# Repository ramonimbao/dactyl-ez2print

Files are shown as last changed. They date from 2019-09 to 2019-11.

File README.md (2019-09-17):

# Dactyl EZ-to-Print

An easy-to-print ortholinear [dactyl](https://github.com/adereth/dactyl-keyboard)-like keyboard that requires no support! An accompanying blog post can be found [here](https://ramonimbao.github.io/ergodox-easy/).

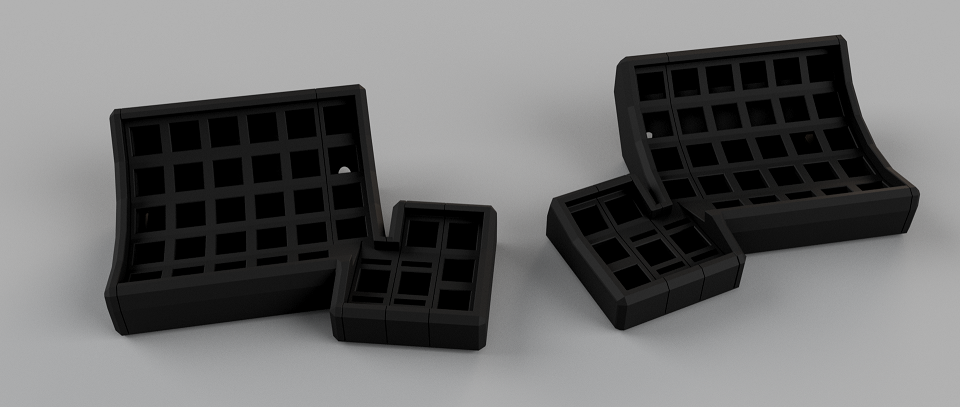
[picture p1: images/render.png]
Left side 3D printed


## Printing

Print the STL files as oriented. No support generation required. If exported from Fusion 360, a certain face of each part has a 0.4 mm chamfer to account for [elephant's foot](https://all3dp.com/2/elephant-s-foot-3d-printing-problem-easy-fixes/). Orient the part such that that face is the bottom.

## Hardware

These files were designed for the blue Arduino Pro Micro and the [RS Pro 805-1661 4-pole composite video jack](https://octopart.com/8051661-rs+pro-103323509) in mind, which is a mistake because I thought those were TRRS jacks! Anyway, besides those two and the 3D prints, the additional hardware you need are:

- 1× M3×25 countersunk head screw
- 10× M3×16 countersunk head screw
- 2× M3×10 countersunk head screw
- 2× M3×8 countersunk head screw

Quantities are for one half only.

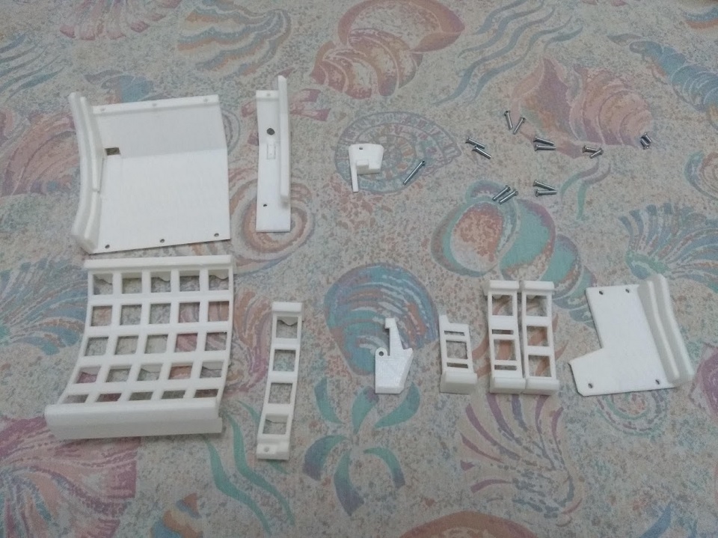
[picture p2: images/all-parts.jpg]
All parts


## Assembly

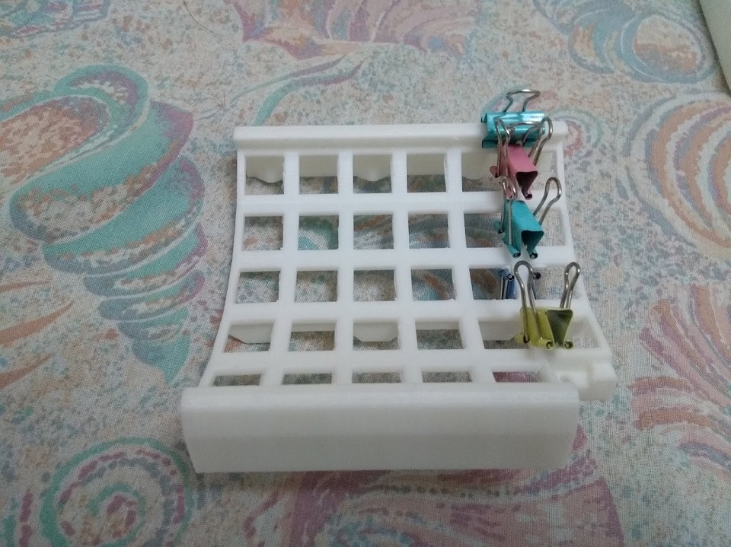
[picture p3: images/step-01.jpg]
Step 1


Glue `Column_TGB` to `Columns_Alpha`. Here, I used some bulldog clips to align everything before gluing.

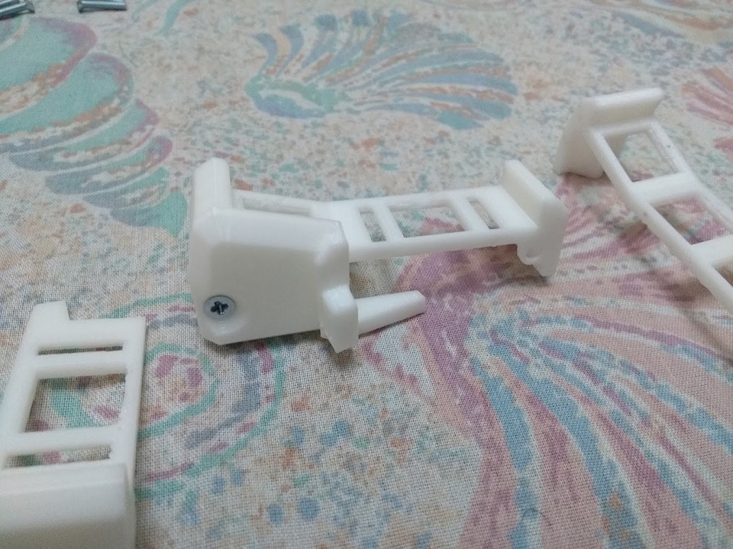
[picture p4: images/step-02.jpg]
Step 2


Use an M3×10 screw to connect `ThumbCluster_B` to `Cap_Mini`.

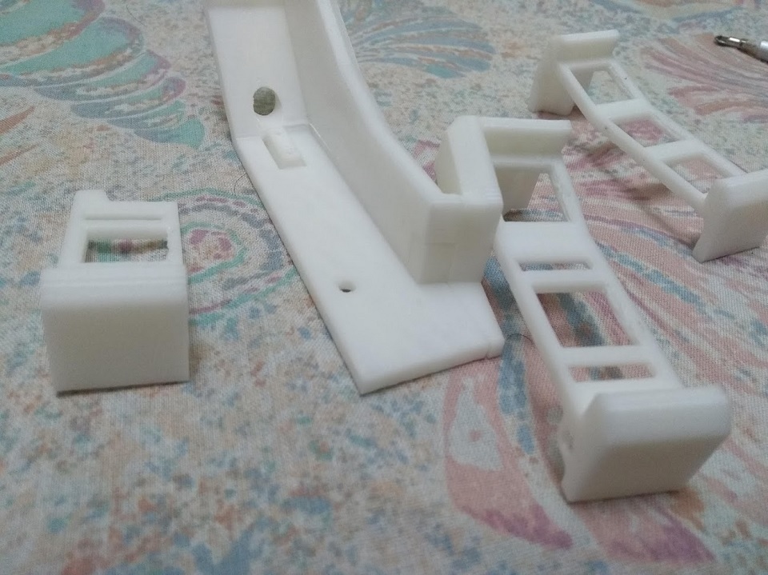
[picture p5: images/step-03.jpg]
Step 3


Slot the subassembly onto `Cap_TGB`.

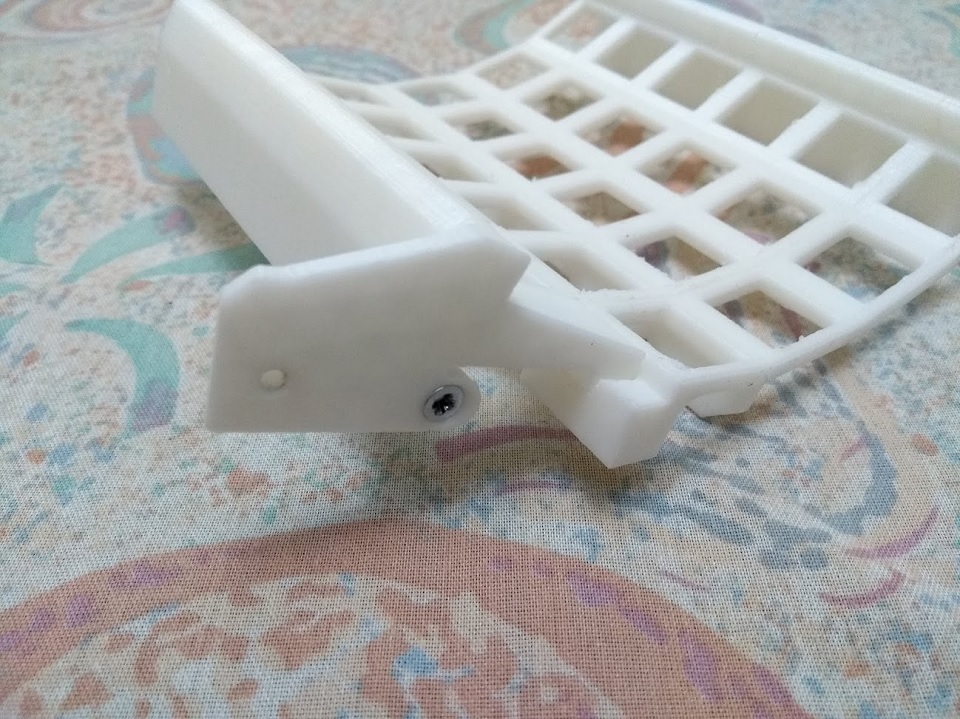
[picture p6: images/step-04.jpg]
Step 4


Use an M3×10 screw to connect `SmallCap` to the alpha columns subassembly that was glued together.

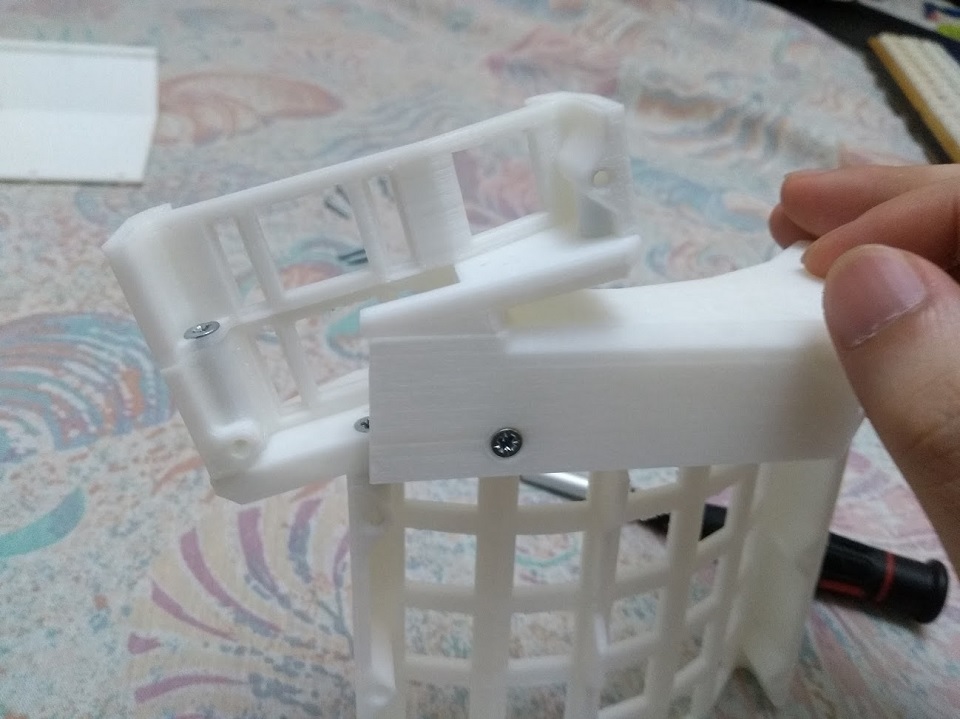
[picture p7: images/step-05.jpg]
Step 5


Use an M3×25 screw to connect the thumb cluster subassembly to the alpha columns, making sure to sandwich `ThumbCluster_A` between them.

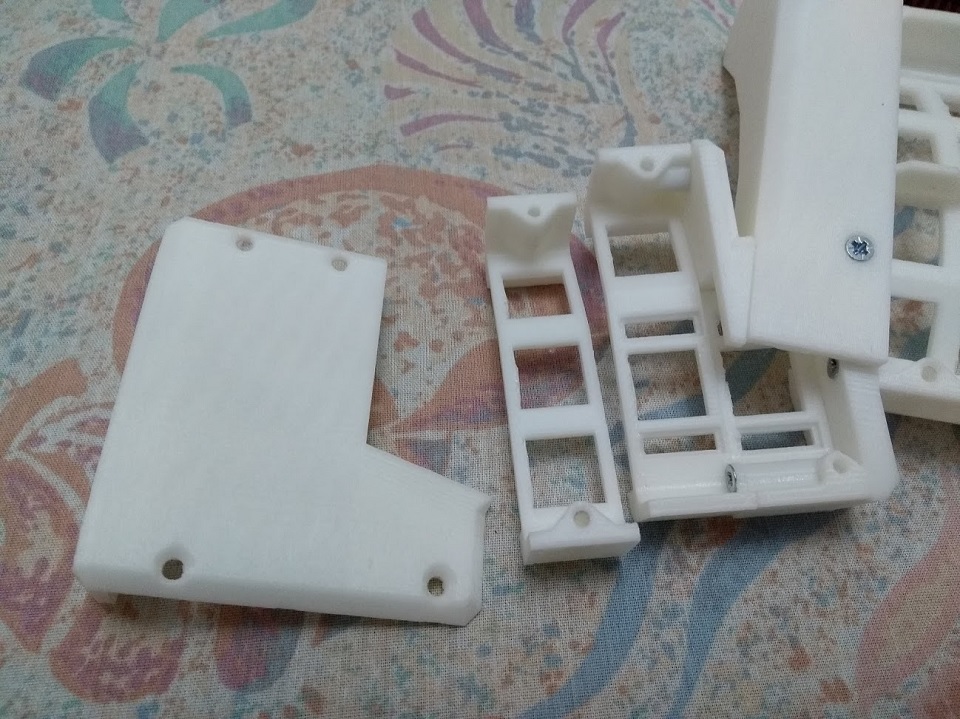
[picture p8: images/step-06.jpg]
Step 6


Use two M3×16 screws and two M3×8 screws to connect the whole subassembly, `ThumbCluster_C` and `Cap_ThumbCluster`. The two M3×16 screws are for the back of the thumb cluster while the two M3×8 screws are for the front.

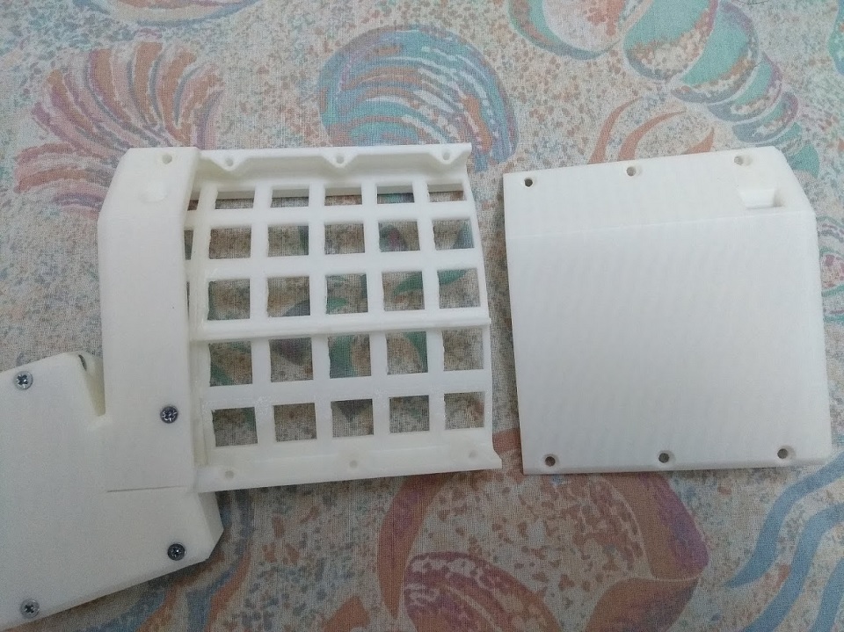
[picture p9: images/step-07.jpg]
Step 7


Finally, connect the whole assembly and `Cap_Alpha` using M3×16 screws. You're done!

## License

The files and the source are licensed under GNU GPLv3. Please see the [LICENSE.md](LICENSE.md) for more details.

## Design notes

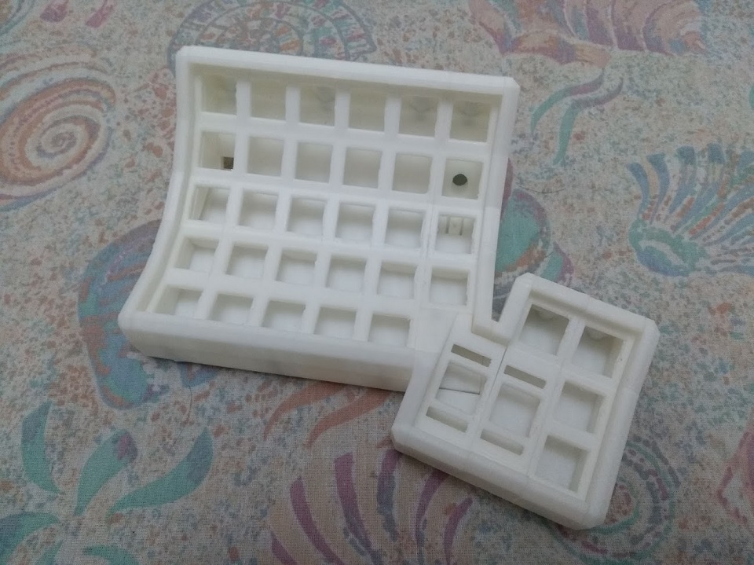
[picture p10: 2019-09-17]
images/complete.jpg

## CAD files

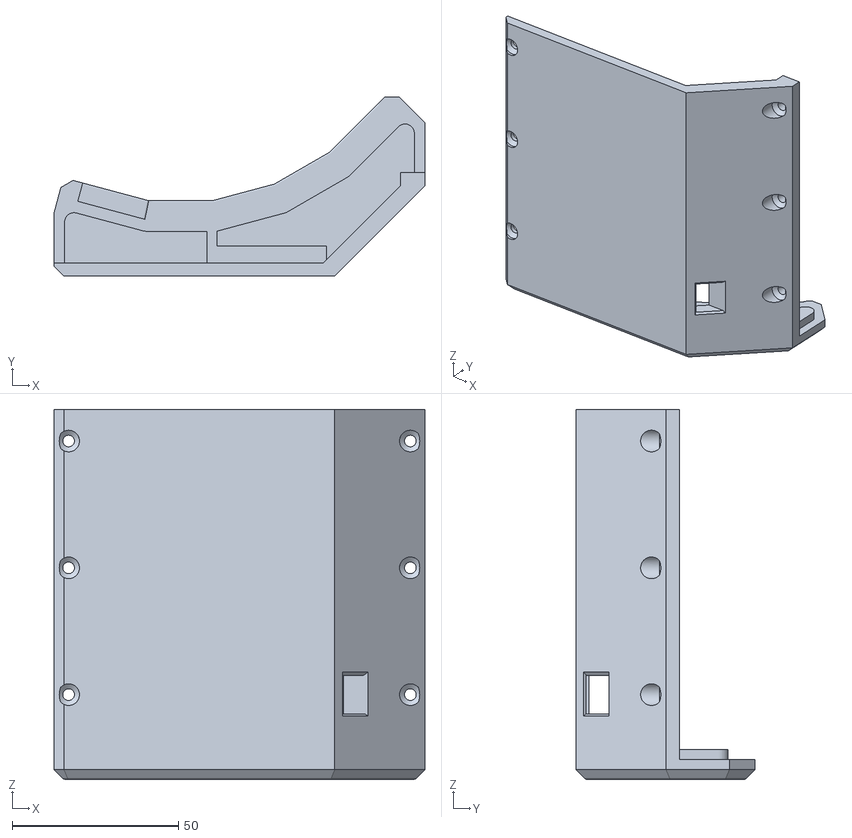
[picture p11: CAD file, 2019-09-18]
STL/left-hand/LH_Cap_Alpha_Ergodox.stl
111.5 x 53.9 x 111.3

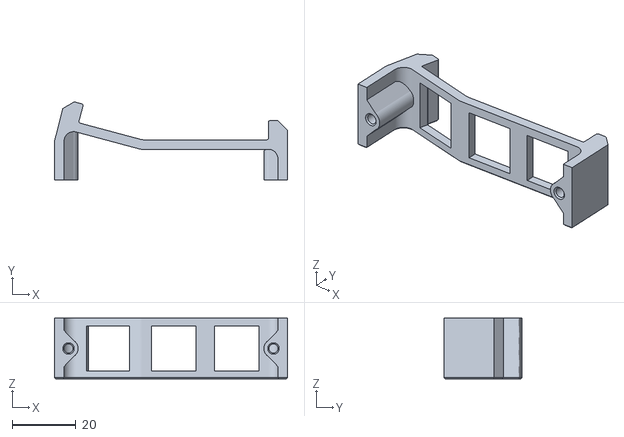
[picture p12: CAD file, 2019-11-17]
STL/right-hand/RH_ThumbCluster_C.stl
73.2 x 24.6 x 19.1

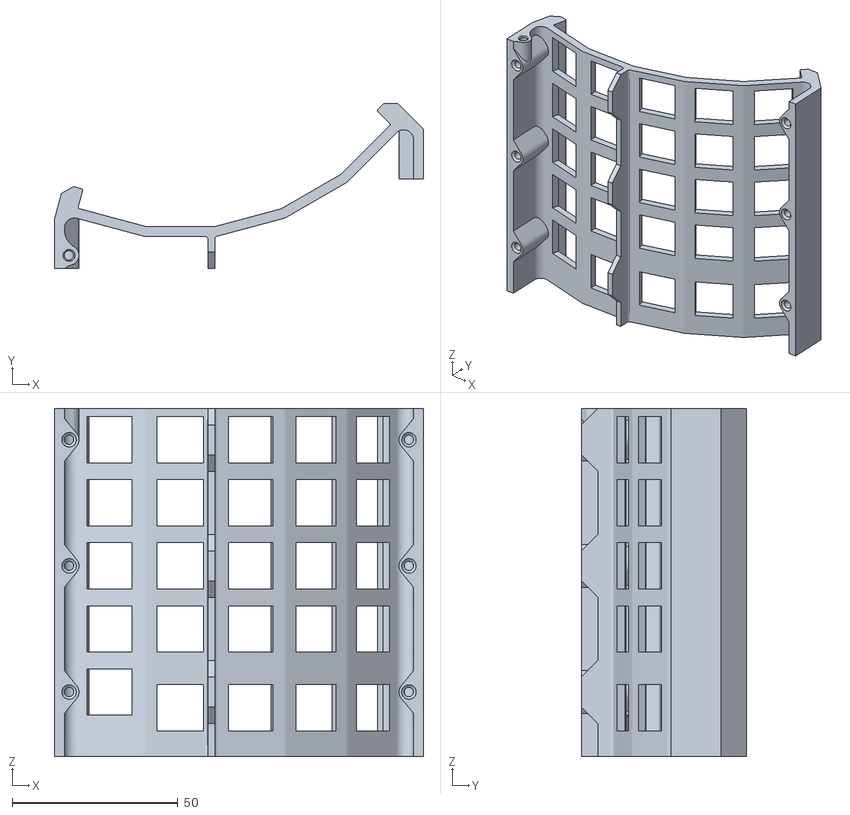
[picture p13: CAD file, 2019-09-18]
STL/left-hand/LH_Columns_Alpha_Ergodox.stl
111.5 x 49.9 x 105.3

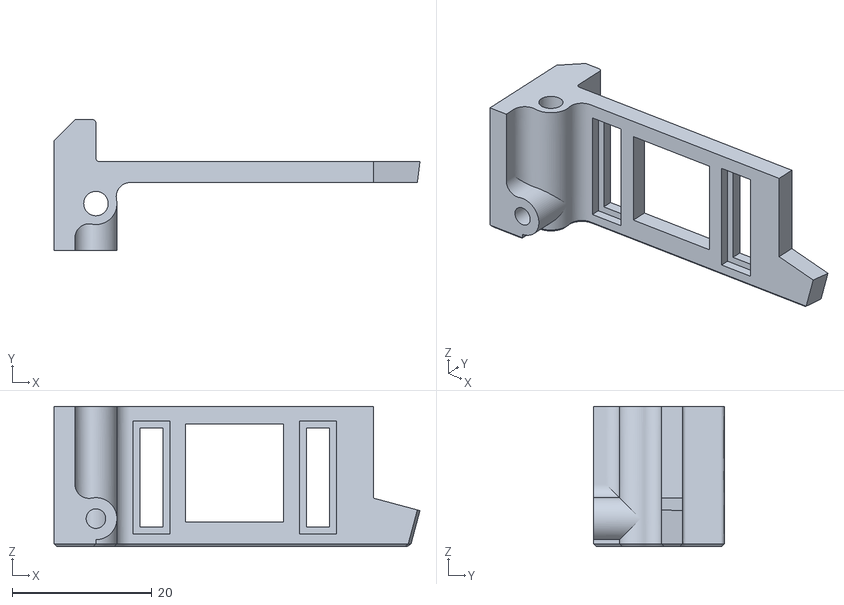
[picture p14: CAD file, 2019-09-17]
STL/left-hand/LH_ThumbCluster_A.stl
52.3 x 18.7 x 20.1

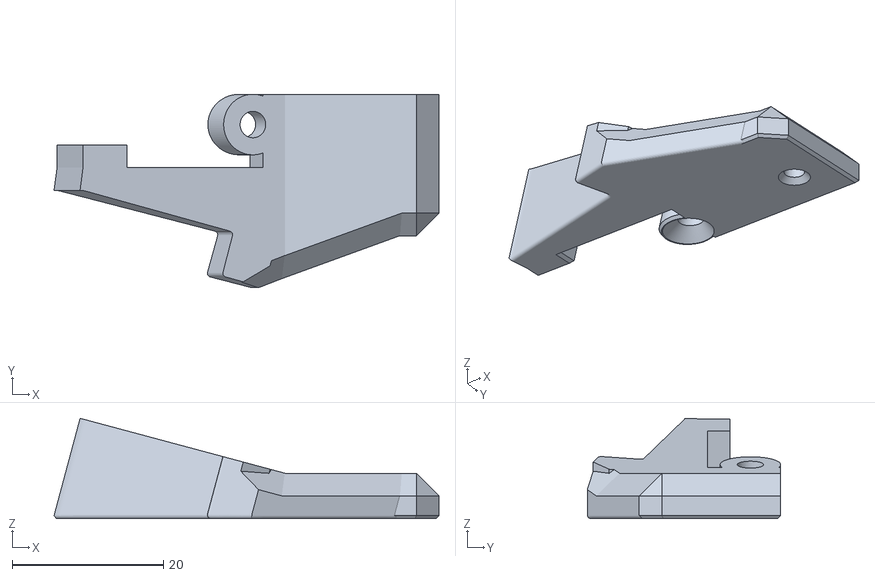
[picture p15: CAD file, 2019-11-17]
STL/right-hand/RH_SmallCap.stl
50.9 x 25.6 x 13.3

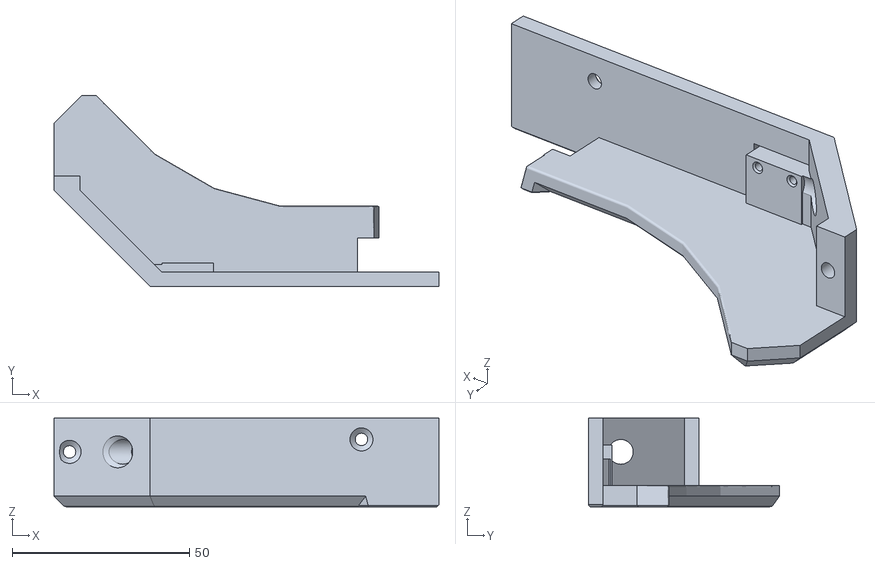
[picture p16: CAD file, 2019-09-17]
STL/left-hand/LH_Cap_TGB.stl
108.7 x 53.9 x 25.1

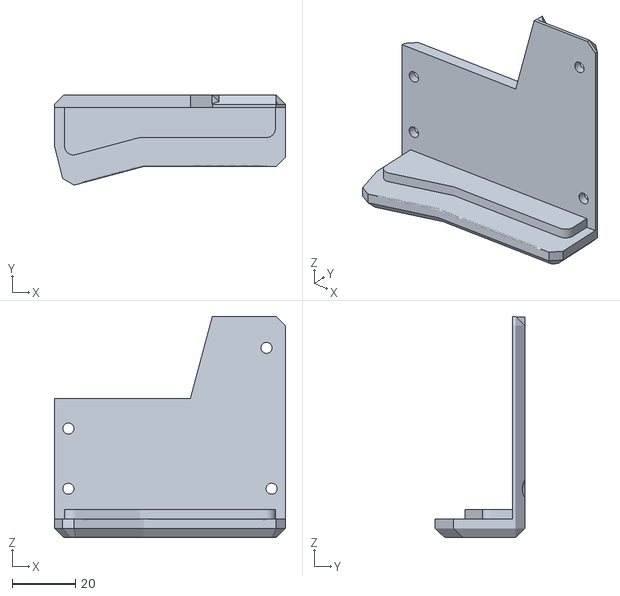
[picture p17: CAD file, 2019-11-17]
STL/right-hand/RH_Cap_ThumbCluster.stl
73.2 x 28.6 x 70.2

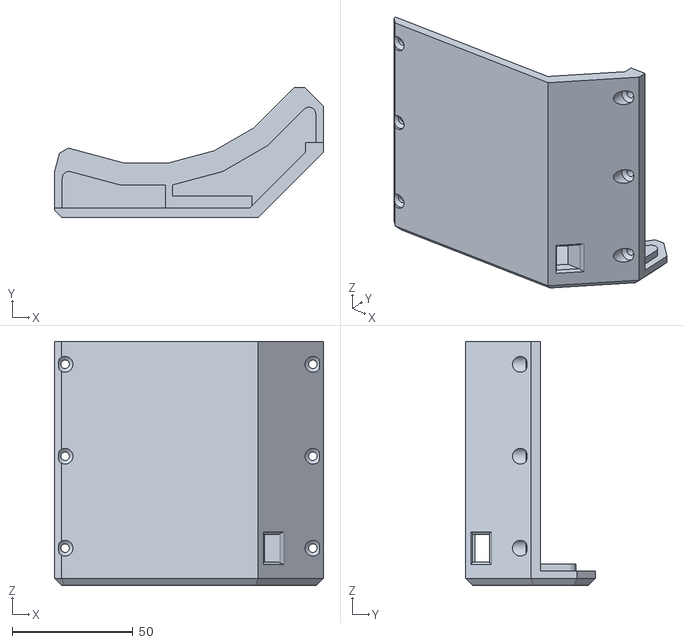
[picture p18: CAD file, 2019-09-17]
STL/left-hand/LH_Cap_Alpha.stl
111.5 x 53.9 x 101.2

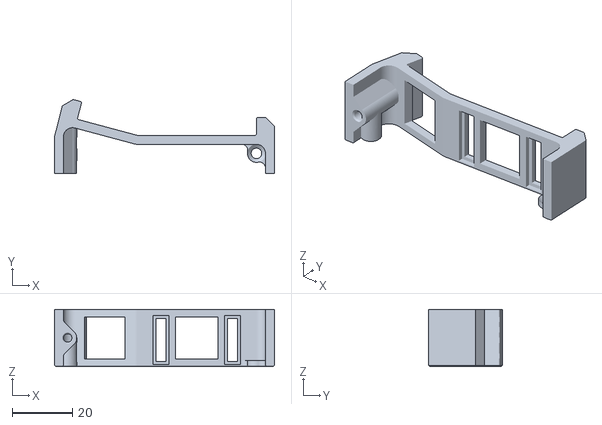
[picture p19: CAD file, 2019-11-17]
STL/right-hand/RH_ThumbCluster_B.stl
73.2 x 24.6 x 19.1

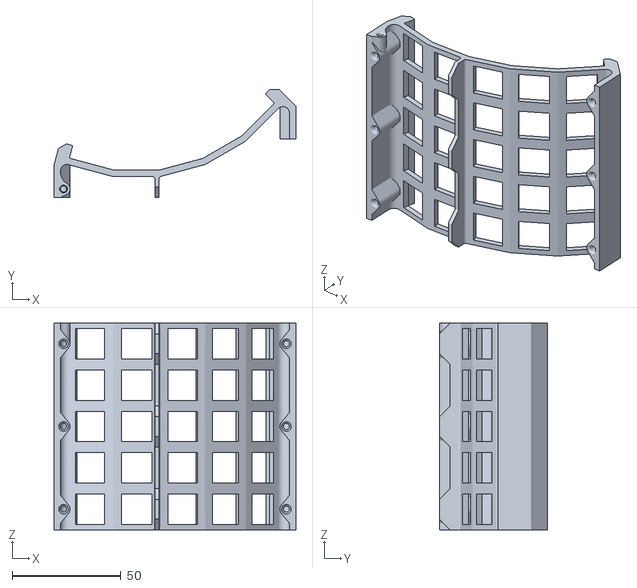
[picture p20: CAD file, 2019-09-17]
STL/left-hand/LH_Columns_Alpha.stl
111.5 x 49.9 x 95.2

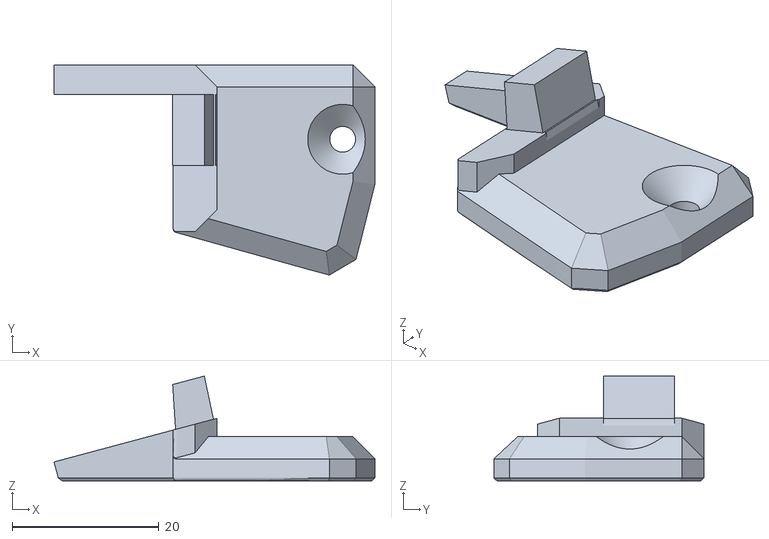
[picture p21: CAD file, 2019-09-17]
STL/left-hand/LH_Cap_Mini.stl
43.7 x 28.6 x 14.3

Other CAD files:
STL/right-hand/RH_Cap_Alpha_Ergodox.stl
STL/left-hand/LH_Cap_ThumbCluster.stl
STL/right-hand/RH_Columns_Alpha_Ergodox.stl
STL/left-hand/LH_ThumbCluster_C.stl
STL/right-hand/RH_Cap_TGB.stl
STL/right-hand/RH_Columns_Alpha.stl
STL/right-hand/RH_ThumbCluster_A.stl
F360/Dactyl-EZ2Print-Ergodox.f3d
F360/Dactyl-EZ2Print.f3d
STL/left-hand/LH_Column_TGB.stl
STL/left-hand/LH_SmallCap.stl
STL/left-hand/LH_ThumbCluster_B.stl
STL/right-hand/RH_Cap_Alpha.stl
STL/right-hand/RH_Cap_Mini.stl
STL/right-hand/RH_Column_TGB.stl

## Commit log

2019-09-18 Add ergodox version with 1.5u mods
    [Cap_Alpha_Ergodox.stl, Columns_Alpha_Ergodox.stl, Dactyl-EZ2Print-Ergodox.f3d]
2019-09-18 Correct 1.25u mods to 1.5u mods
    [Cap_Alpha_Ergodox.stl, Columns_Alpha_Ergodox.stl, Dactyl-EZ2Print-Ergodox.f3d]
2019-11-17 Add right hand STL files
    [LH_Cap_Alpha.stl, LH_Cap_Alpha_Ergodox.stl, LH_Cap_Mini.stl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]
